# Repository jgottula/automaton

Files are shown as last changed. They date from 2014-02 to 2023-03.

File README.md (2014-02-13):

automaton
=========
`automaton` is a trip computer for your car. Utilizing breakthrough 1990s
technology, it will enable instantaeous visibility into various aspects of your
car's performance, such as engine data, fuel efficiency estimates, and speed
statistics. In addition, state-of-the-art SD card technology is now enabling the
sort of data logging and analysis that bored drivers of the past could only
dream about. `automaton` will undoubtably provide multiple hours of fun to
offset the innumerable hours its users spend driving.

what is it
----------
**Hardware** currently consists of a professionally fabricated PCB, mounted in a
sturdy project box with an RGB-backlit 128x64 graphics LCD for output and a
series of pushbuttons for input. IO connections on the board include **OBD-II**
(of course), **MicroSD** (for data logging), **MiniUSB** (for debug logging),
**JTAG** (for programming/debugging), and **PDI** (also for
programming/debugging).

**Firmware** consists of the AVR Xmega firmware program written in C that
operates the primary microcontroller.

**Software** will consist of PC-based Python scripts that can analyze logged
data to produce graphs and other statistical eye candy.

project status
--------------
**Hardware** is in its third version: first came the breadboard version that
used an AVR ATmega and the STN1110 OBD chip; second came a largely similar, but
more permanent, iteration built on perfboard; and now, the hardware is on a PCB
as described in the previous section. Hardware is essentially finalized, but a
second revision of the PCB may be produced if enough errata are found in the
first.

**Firmware** is where development is currently taking place. This is where most
of the work will be done, and a great deal of code needs to be ported over from
the older version.

**Software** is currently vaporware. Once the firmware is producing data, then
the software can be developed to analyze it.

supported vehicles
------------------
Vehicles must support OBD-II. Any vehicle made after 1996 is required by law to
implement OBD-II. However, the geniuses behind this standard decided that no
less than a half-dozen different physical layer implementations needed to be
developed to transmit the exact same information.

This means that vehicle support is limited by the type of bus in use. Vehicles
made after 2008 are required to support CAN (ISO 15765), so that is what the
current version of `automaton` supports. Future versions could feasibly support
more bus standards, pending developer motivation.

planned features
----------------

- Live data via LCD
- Deferred data analysis via micro SD card and Python scripts
- GPS waypoint logging
- Check Engine Light zapper
- Undocumented OBD-II PID sweeper

hardware and chips
------------------

Hardware is subject to change, but it's pretty locked down at this point.

- Microcontroller: Atmel ATxmega128A3U @ 32MHz (128KB flash; 8KB SRAM)
- CAN transceiver: Microchip MCP2562
- CAN controller: Microchip MCP2515
- Real-time clock: Maxim DS1390U
- GPS module: GlobalTop FGPMMOPA6H
- Debug UART: FTDI FT231XS
- LCD: 128x64 ST7565 graphic RGB-backlit LCD

compiling
---------
This project uses Avery Pennarun's implementation of D. J. Bernstein's `redo`
build system.

To build the `automaton` AVR firmware program, install `redo` and simply run
`redo all`. To clean the project directory, run `redo clean`.

To load the firmware onto the microcontroller, obtain a hardware programmer and
run `redo load`. You will almost certainly need to modify the build script for
this to work.

The build script may need to be modified for your system configuration. To do
so, you need only edit the `default.do` file in the project's root directory. As
`redo` uses posix shell scripts, a basic understanding of shell scripting is
sufficient to modify the build script to your purposes.

license
-------
This project is licensed under the terms of the simplified (2-clause) BSD
license. For more information, see the `LICENSE` file contained in the project's
root directory.

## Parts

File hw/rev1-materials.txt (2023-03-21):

bill of materials

digikey		WebID 50408393, AccessID 27979
adafruit	FGPMMOPA6H, LCD
mdfly		6x6x9 buttons, button caps
frys		idc 12-pin crimp connectors
home depot	velcro mount
lowes		PCB screws
my stuff	78L05, headers, ribbon cable

costs:
osh park	$53.65 (3x PCB r1)
digikey		~$49.94 (1x Bill of matls) + ~8.07 (replacement LED & microSD)
			+ ~$14.95 (GPS antenna and SMA connector)
adafruit	$18.95+ (1x LCD)
adafruit	$33.77 (1x GPS)
home depot	$3.21 (1x Velcro 4x2" Industrial StrengthStrips)
lowes		$4.46 (20x #4x1/4" PCB screw)
frys		$ ()

enclosure		1591XXCBK
	alt:		1951XXCSBK (econo version)
	alt:		1591XXBBK (slightly smaller)
pcb screw		6004 (qty: 4)
power supply	R-78E3.3-0.5
	alt:		ROF-78E3.3-0.5SMD-R
5v regulator	L78L05ACZ
avr xmega		ATXMEGA128A3U
lcd				adafruit st7565 128x64 rgb negative (owned already)
gps				FGPMMOPA6H
	alt:		Venus638FLPx-L
can controller	MCP2515
can transceiver	MCP2562
usb/serial		FT231XS
rtc				DS1390U-33+T&R
usb port		0675031020
sd socket		5031820832 (NOT 5033980891!)
battery holder	BLP2032SM-GTR (rather large... smaller batt or vertical holder?)
avr xtal		ATS16B
can xtal		ATS250B-E
rtc xtal		CFS206-32.768KEZB
button			B3F-1050
	cap:		B32-2000/B32-2010 (5mm round)
	cap:		B32-1060/B32-1010 (4mm square)
reset button	???
piezo			???
power switch	???

NEED: 12-pin IDC ribbon cable terminator (female) for LCD connection (11 pins)

LED 1206 R/1.8	LH N974-KN-1
LED 1206 G/2.2	LG N971-KN-1

R 1206    12	RC3216J120CS
R 1206    27	RC3216J270CS
R 1206    68	RC3216J680CS
R 1206   120	RC3216J121CS
R 1206    1k	RC3216J102CS
R 1206  1.5k	RC3216J152CS
R 1206  4.7k	RC3216J472CS
R 1206   10k	RC3216F103CS

C 1206 5.6pF	CL31C5R6CBCNNNC
C 1206  18pF	CL31C180JBCNNNC
C 1206  47pF	CL31C470JCCNNNC
C 1206   1nF	CL31B102KBCNNNC
C 1206  10nF	CL31B103KBCNNNC
C 1206 100nF	CL31B104KBCNNNC
C 1206 330nF	CL31B334KBFNNNE
C 1206   1uF	CL31B105KAHNNNE
C 1206 4.7uF	CL31F475ZOFNNNE
C 2x5  4.7uF	ESH475M050AC3AA
C 2x5   10uF	ESK106M016AC3AA

L 1812  bead	HF50ACB453215-T
L 1812  10uH	CM453232-100KL

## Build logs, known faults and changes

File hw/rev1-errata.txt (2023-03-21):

rev1 errata

major

- GPS UART pin assignments on the XMEGA are idiotic (should be GPS_TX on PD2 and
  GPS_RX on PD3)
  - WORKAROUND: cut PD1, PD2, PD3, rewire so that PD1 is CAN_STANDY, and PD2 and 
    PD3 are GPS_TX and GPS_RX

- Upper-right PCB mount hole should be at (99.5, 51) mm but is actually at
  (99.5, 50) mm
  - WORKAROUND: use 3 mounting screws

- MOSFETs for LCD backlight are all wrong: currently they have drain connected
  to +3.3V and source connected thru resistor to BL- pin; should have source
  connected to GND, and drain connected to resistor/BL- pin
  - WORKAROUND: use MCU IO ports directly

minor

- Insufficient clearance between the 3.3v regulator and the box of the OBD
  right-angle header (very tight clearance with 5v regulator as well)

- USB connector protrudes too far: makes inserting PCB into box difficult

- Battery connector impinges on capacitor to the right; also, the negative
  terminal is completely beneath the plastic and therefore difficult to solder

- Reset button solder pads are too tiny (don't extend out enough) to make good
  electrical connections

- LED resistors are too high-value: switch to 110ohm for green (FTDI RX, pwr)
  and 150ohm for red (FTDI TX)

- Need to label all headers ("JTAG", "LCD", etc) AND label all pin 1's

- Add test points for all voltages (GND, 3V3, 5V, 12V)

- Add SMA/MCX connector for GPS external antenna (APAMP-107 for $7.80)

- Pads for MicroSD detect/ground terminals are too tiny

- Reconsider which ports need to be externally accessible thru side of box;
  consider making ports on the backside of the PCB that protrude thru box bottom

- Add convenient header for non-car power supply

component changes

- Mini USB connector: switch for one that's easier to solder
  - switch to micro USB (even type C?) if possible

- Battery connector: switch for one that's easier to solder (upright?)

- Crystals: use smaller package

- Capacitors: don't use shitty thru-hole electrolytics

features

- Input phy for OBD signal protocols other than CAN (test these with breadboard)
  - SAE J1850 PWM
  - SAE J1850 VPW
  - ISO 9141-2 (same phy as ISO 14230 KWP2000)

- Battery sense analog input
  - use precision resistors for voltage divider
  - base it on STN1110 figure 5

protection

- Power inputs (before regulation)
  - overcurrent: fuse/resistor
  - reversal: blocking diode
  - overvoltage: zener diode
  - ESD: TVS diode

- Vcc power rails (3.3 and 5.0)
  - reversal: blocking diode
  - overvoltage: zener diode

- External IO pins
  - overcurrent: fuse/resistor
  - overvoltage: zener diode (make sure that this won't mess up bus stuff!)
  - ESD: zener diodes (see STN1110 datasheet)

- AVR reset pin
  - overcurrent: 1k resistor directly on RESET pin

- Make sure that all LCD input/output is up to spec

- Check all IC datasheets and ensure that caps & inductors are up to spec

- Use low-ESR caps for all power caps

CHECK THESE THINGS!

- All actual component footprints: check for overlaps!

- Pin headers need pin 1 marked in silkscreen

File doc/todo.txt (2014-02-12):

automaton
todo list

ui pages:
- trouble code viewer
- trouble code clearer
- proprietary PID scanner
  (brute force modes and PIDs; try the AT MA command, page 40 of the ELM327 ds)
  (also try AT SH to address commands to other bus endpoints/controllers)

power saving, in order of savings:
- AVR: turn off peripherals not in use
- AVR idle: use low-power mode
- screen off
- sleep mode: put STN and AVR in low-power mode
- off switch
- disconnect obd cable

graphs:
- use partial vertical blocks to do bar graphs

grouping:
- put die, reset, wdt, power stuff under one directory
- keep mcusr value in there somewhere

clock/voltage:
- run at 3.3V
  - done
    - switch crystal from 20MHz to 12MHz
    - resolder FTDI: 3V out, 3V signal level
    - change F_CPU
    - rewire regulators
    - LCD to 5V
    - MCP2551 to 5V
    - brownout detect level to 2.7
    - remove 4050
    - update time-based enums
  - to do
    - LED resistors

alarm:
- use the same timer for multiple alarms

pc uart:
- variadic logging function with log level parameter?
- use ANSI colors for different log levels

code:
- handle all TODO's and #warning's
- standard greppable comment for REMOVE ME etc

debug:
- in UART code, _BREAK() then die() on errors (eg: dev is neither 0 nor 1)

avarice:
- recompile with atmega324a support

redo:
- load: program the eeprom
- *.o:  do .dep generation in one step (as in manual)
- when avr-gcc-4.8 is fixed, add:
  - -Waddr-space-convert
  - -fno-diagnostics-show-caret

button:
- read up and get RC values for hw debounce

algo/fifo & io/uart:
- read assembly generated by gcc and ensure that atomic/interrupt-safe functions
  don't take dangerous shortcuts and also don't over-access memory

storage:
- replace fat32 with something that won't explode if the power goes out
- my idea: append-only filesystem for logging:
  - two superblocks, updated alternately, with revision number and checksum
  - use most recent version that is valid
  - superblock says what the latest valid block is
  - to append a block: do the write, then update the superblock
  - worst case, lose the latest block only

time:
- add profiling interface
  - use TIMER1 to count cycles, probably
  - profiling targets:
    - all ISRs (especially TIMER0_COMPA with button_update)
    - all delay/alarm code (test for correctness)

lcd/hd44780:
- implement timeout for hd44780_busy_wait
- use 4-bit bus

lcd/lcd:
- make friendly functions to manipulate individual bits of param state
- custom font api

stdio:
- implement a smaller/simpler vfprintf(); override?

power:
- use sleep instead of spinning or _delay_xx
- go to 3.3 volts

hardware:
- use leds everywhere
  - power
  - tx/rx on each UART
  - tx/rx on each OBD interface
  - r/w on SDcard
  - sck on SPI bus
  - buttons?

test:
- time/alarm
- algo/fifo
- io/uart
- io/spi
- lcd/hd44780

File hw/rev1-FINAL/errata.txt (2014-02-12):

rev3 errata

1. GPS UART pin assignments on the XMEGA are idiotic (should be GPS_TX on PD2
   and GPS_RX on PD3)
   MITIGATION: cut PD1, PD2, PD3, rewire so that PD1 is CAN_STANDY, and PD2 and
   PD3 are GPS_TX and GPS_RX (not easy but probably doable)
   MITIGATION: bitbang the uart (nope)

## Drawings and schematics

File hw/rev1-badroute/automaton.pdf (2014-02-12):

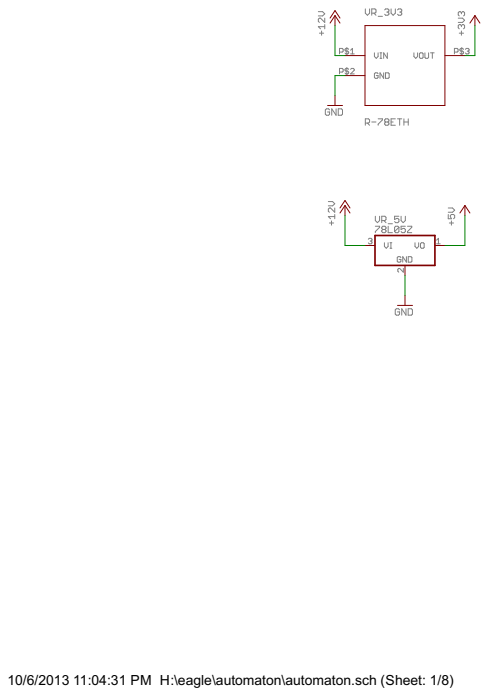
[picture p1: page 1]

10/6/2013 11:04:31 PM H:\eagle\automaton\automaton.sch (Sheet: 1/8)

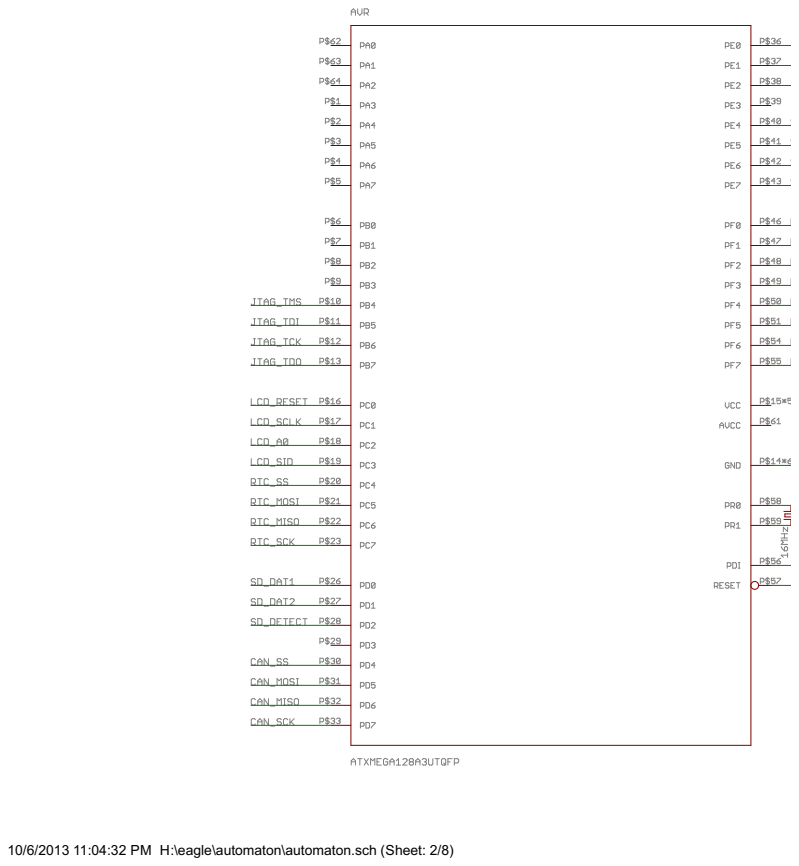
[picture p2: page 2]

10/6/2013 11:04:32 PM H:\eagle\automaton\automaton.sch (Sheet: 2/8)

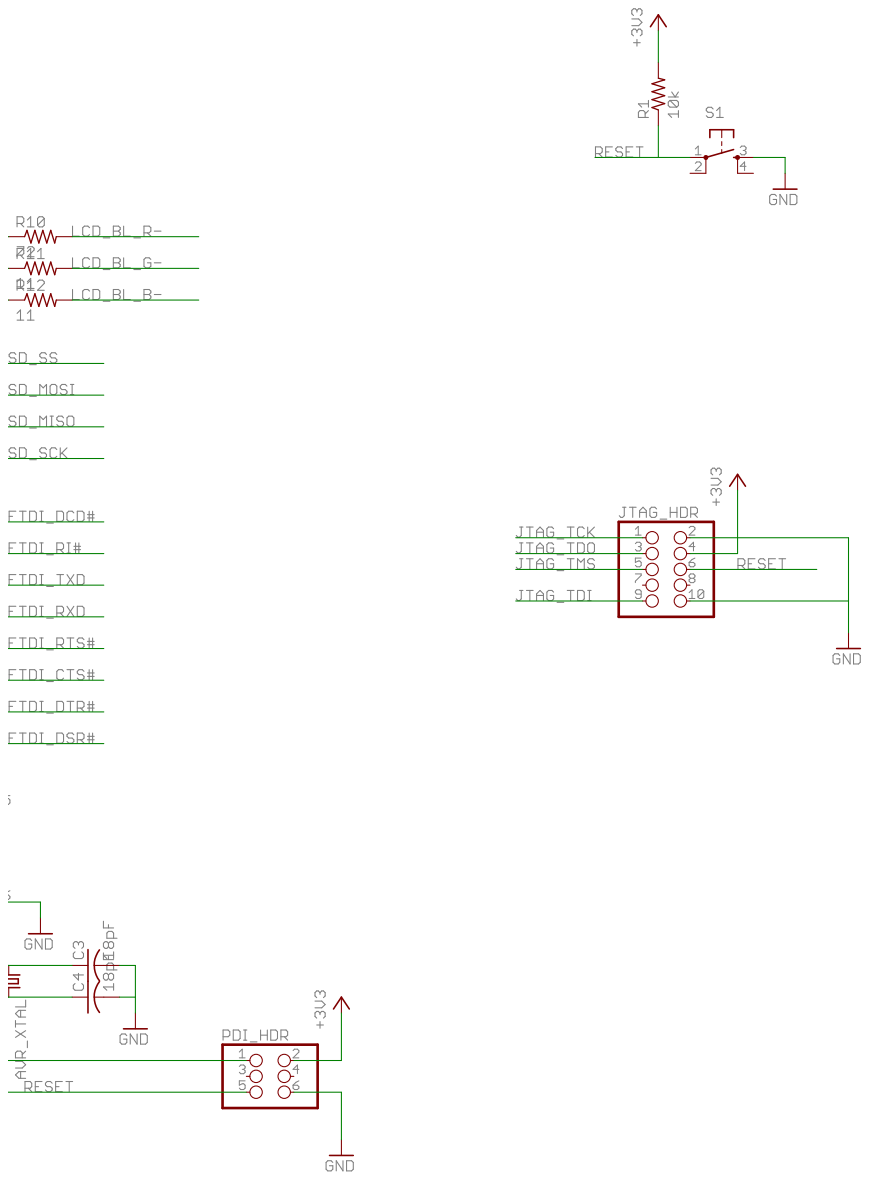
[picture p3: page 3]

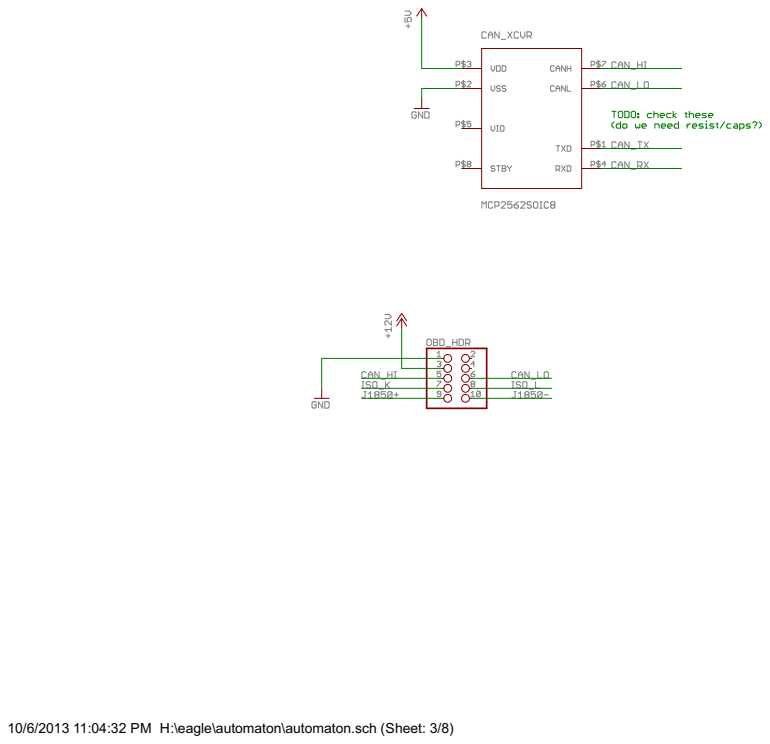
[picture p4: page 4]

10/6/2013 11:04:32 PM H:\eagle\automaton\automaton.sch (Sheet: 3/8)

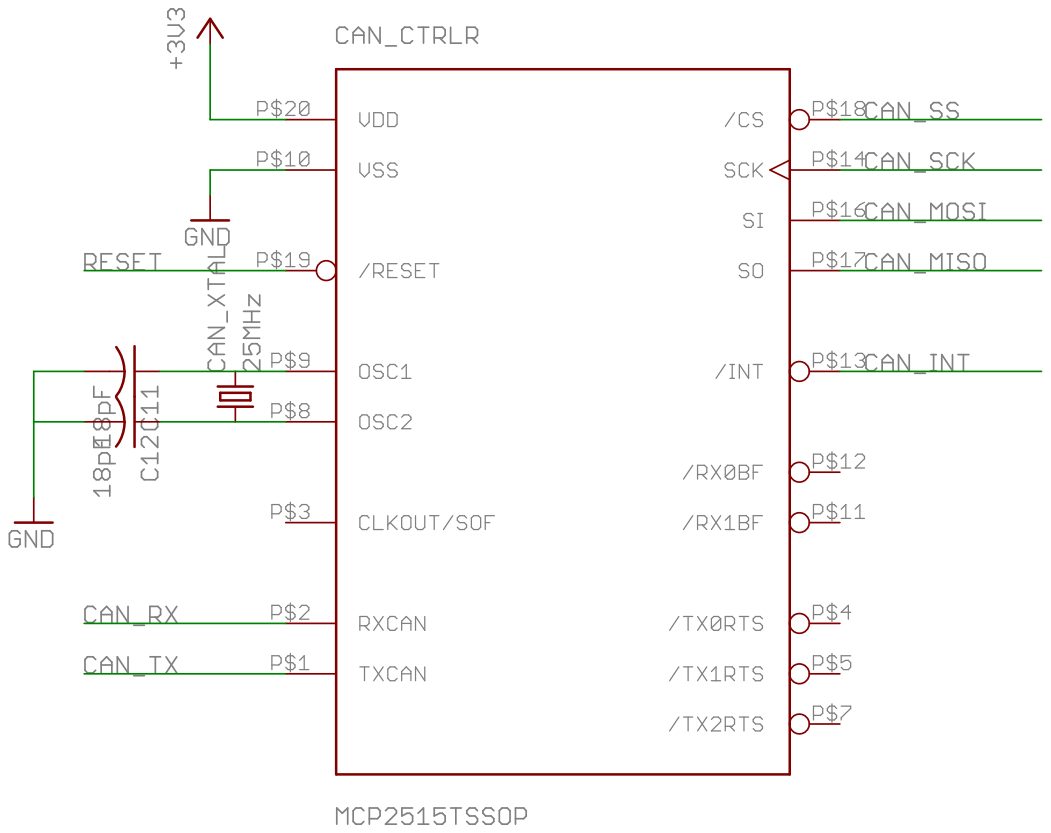
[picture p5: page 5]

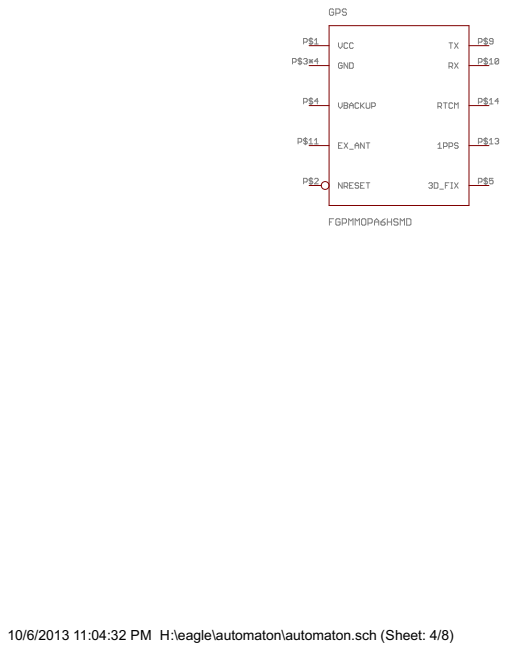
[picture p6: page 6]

10/6/2013 11:04:32 PM H:\eagle\automaton\automaton.sch (Sheet: 4/8)

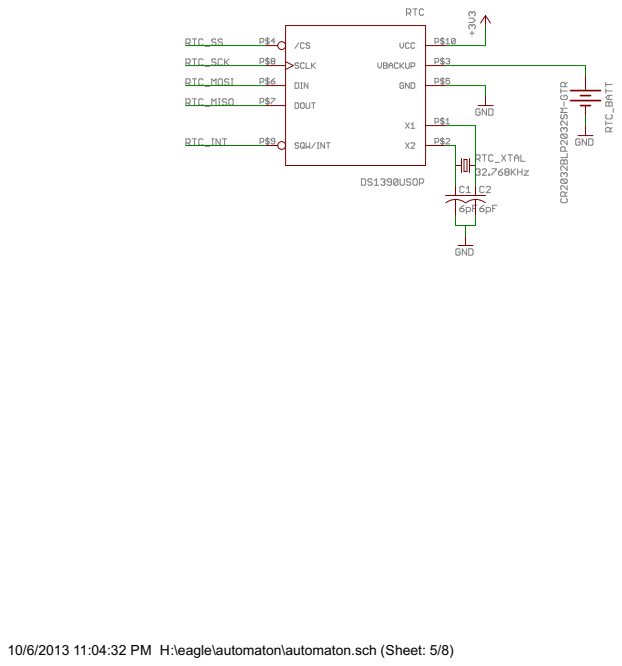
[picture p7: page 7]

10/6/2013 11:04:32 PM H:\eagle\automaton\automaton.sch (Sheet: 5/8)

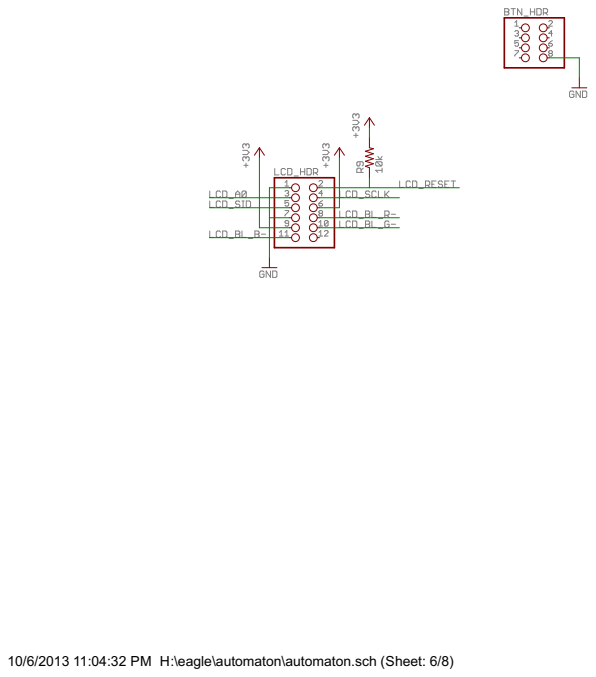
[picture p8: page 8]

10/6/2013 11:04:32 PM H:\eagle\automaton\automaton.sch (Sheet: 6/8)

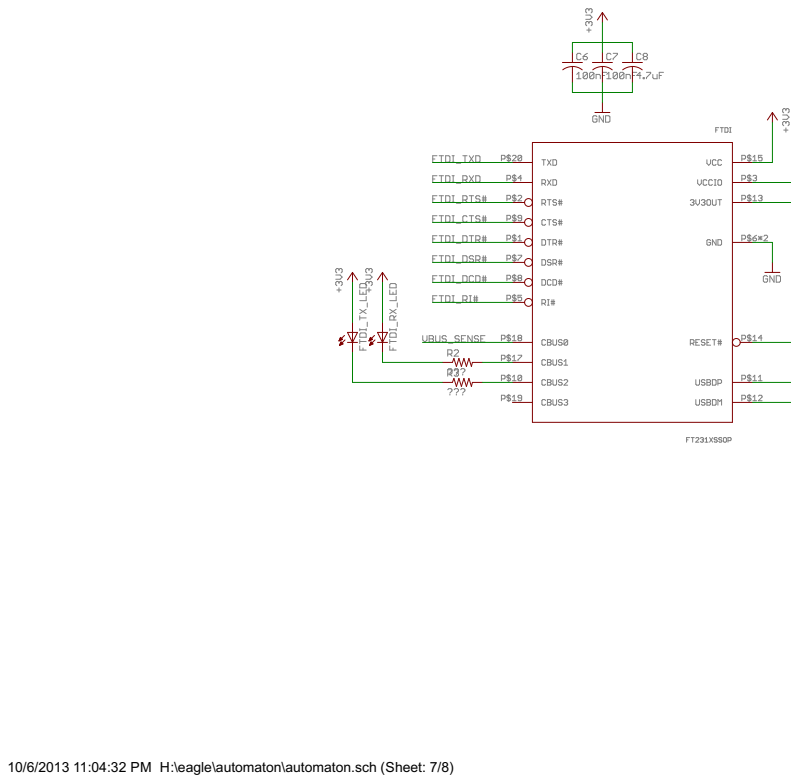
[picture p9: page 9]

10/6/2013 11:04:32 PM H:\eagle\automaton\automaton.sch (Sheet: 7/8)

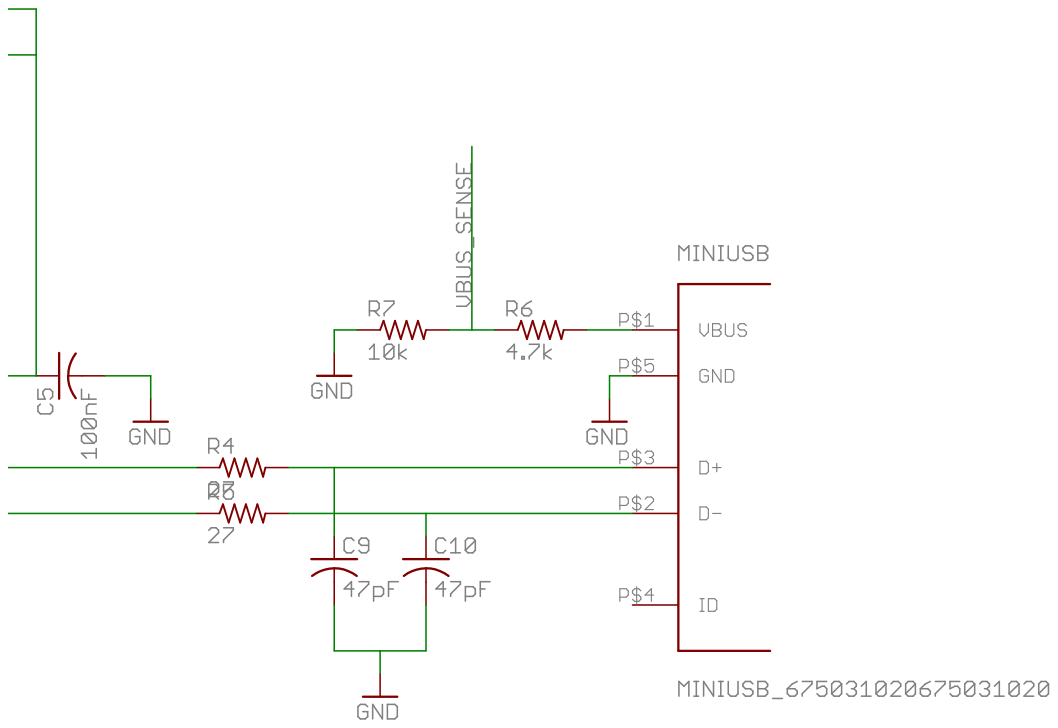
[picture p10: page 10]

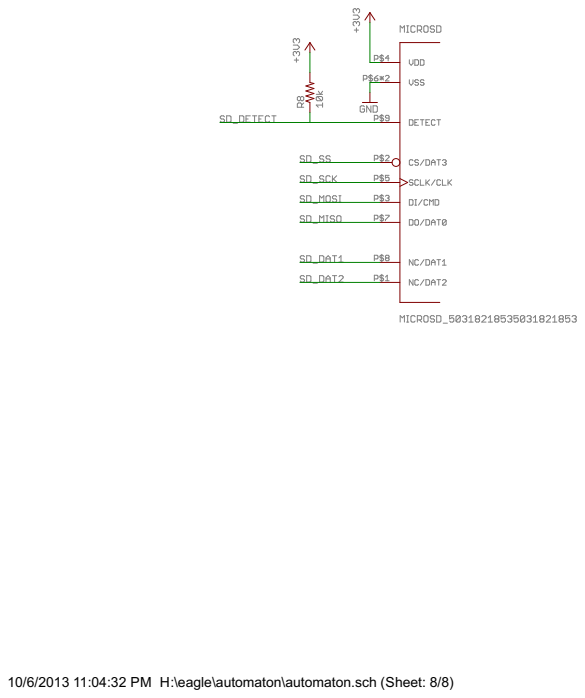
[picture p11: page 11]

10/6/2013 11:04:32 PM H:\eagle\automaton\automaton.sch (Sheet: 8/8)

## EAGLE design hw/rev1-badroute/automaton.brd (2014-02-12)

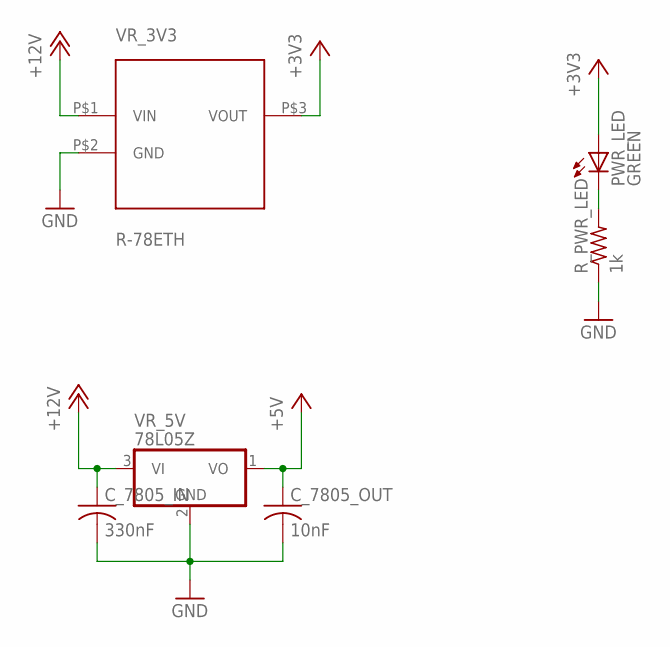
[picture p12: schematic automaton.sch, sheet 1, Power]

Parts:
C_7805_IN: 330nF; C1206
C_7805_OUT: 10nF; C1206
PWR_LED: GREEN; CHIPLED_1206
R_PWR_LED: 1k; R1206
VR_3V3: R-78ETH; R-78E
VR_5V: 78L05Z; TO92

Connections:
+3V3: PWR_LED.A, VR_3V3.P$3 (VOUT); also elsewhere on the board
+5V: C_7805_OUT.1, VR_5V.1 (VO); also elsewhere on the board
+12V: C_7805_IN.1, VR_3V3.P$1 (VIN), VR_5V.3 (VI); also elsewhere on the board
GND: C_7805_IN.2, C_7805_OUT.2, R_PWR_LED.1, VR_3V3.P$2 (GND), VR_5V.2 (GND); also elsewhere on the board
unnamed: PWR_LED.C, R_PWR_LED.2

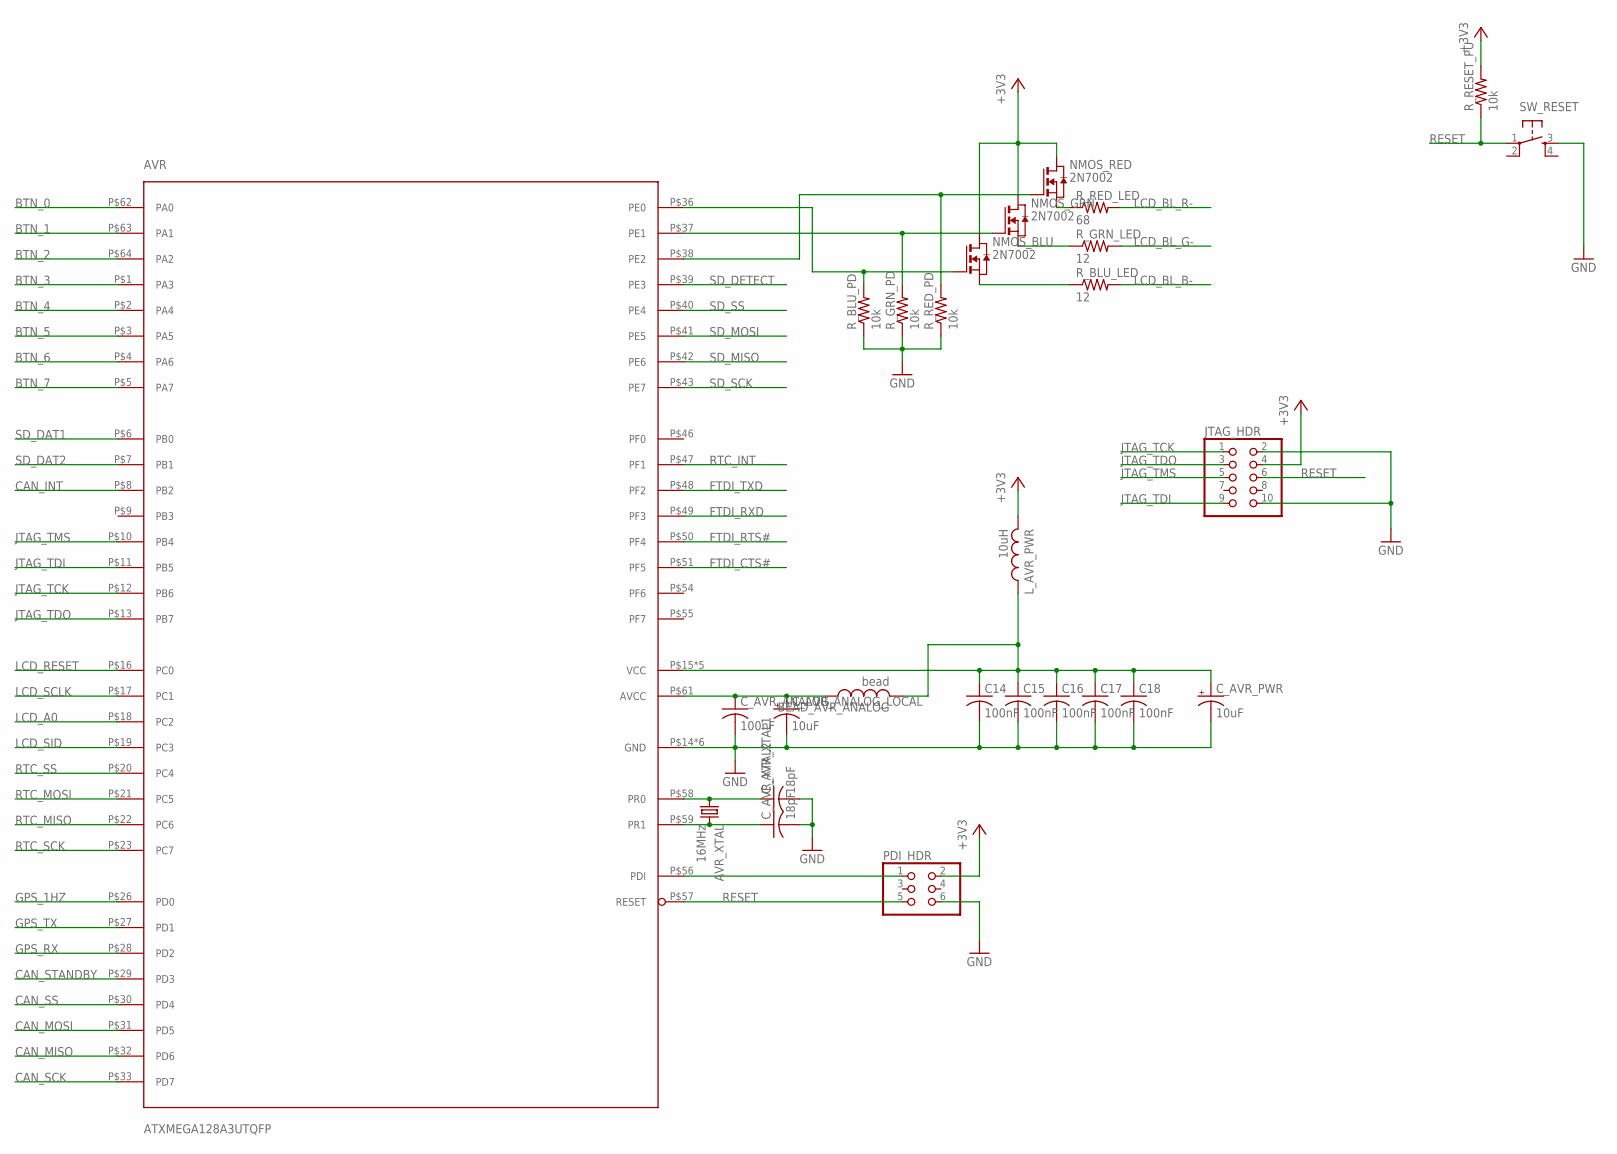
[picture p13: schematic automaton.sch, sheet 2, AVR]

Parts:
AVR: ATXMEGA128A3UTQFP; ATMEL_TQFP64
AVR_XTAL: 16MHz; HC49/S
BEAD_AVR_ANALOG: bead; L1812
C14, C15, C16, C17, C18: 100nF; C1206
C_AVR_ANALOG: 100nF; C1206
C_AVR_ANALOG_LOCAL: 10uF; E2-5
C_AVR_PWR: 10uF; E2-5
C_AVR_XTAL1, C_AVR_XTAL2: 18pF; C1206
JTAG_HDR: PINHD-2X05_2.54; 2X05
L_AVR_PWR: 10uH; L1812
NMOS_BLU: 2N7002; SOT-23
NMOS_GRN: 2N7002; SOT-23
NMOS_RED: 2N7002; SOT-23
PDI_HDR: PINHD-2X03_2.54; 2X03
R_BLU_LED: 12; R1206
R_BLU_PD: 10k; R1206
R_GRN_LED: 12; R1206
R_GRN_PD: 10k; R1206
R_RED_LED: 68; R1206
R_RED_PD: 10k; R1206
R_RESET_PU: 10k; R1206
SW_RESET: TAC_SWITCHSMD; TACTILE_SWITCH_SMD

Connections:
+3V3: JTAG_HDR.4, L_AVR_PWR.2, NMOS_BLU.1 (D), NMOS_GRN.1 (D), NMOS_RED.1 (D), PDI_HDR.2, R_RESET_PU.2; also elsewhere on the board
BTN_0: AVR.P$62 (PA0); also elsewhere on the board
BTN_1: AVR.P$63 (PA1); also elsewhere on the board
BTN_2: AVR.P$64 (PA2); also elsewhere on the board
BTN_3: AVR.P$1 (PA3); also elsewhere on the board
BTN_4: AVR.P$2 (PA4); also elsewhere on the board
BTN_5: AVR.P$3 (PA5); also elsewhere on the board
BTN_6: AVR.P$4 (PA6); also elsewhere on the board
BTN_7: AVR.P$5 (PA7); also elsewhere on the board
CAN_INT: AVR.P$8 (PB2); also elsewhere on the board
CAN_MISO: AVR.P$32 (PD6); also elsewhere on the board
CAN_MOSI: AVR.P$31 (PD5); also elsewhere on the board
CAN_SCK: AVR.P$33 (PD7); also elsewhere on the board
CAN_SS: AVR.P$30 (PD4); also elsewhere on the board
CAN_STANDBY: AVR.P$29 (PD3); also elsewhere on the board
FTDI_CTS#: AVR.P$51 (PF5); also elsewhere on the board
FTDI_RTS#: AVR.P$50 (PF4); also elsewhere on the board
FTDI_RXD: AVR.P$49 (PF3); also elsewhere on the board
FTDI_TXD: AVR.P$48 (PF2); also elsewhere on the board
GND: AVR.P$14 (GND), AVR.P$24 (GND), AVR.P$34 (GND), AVR.P$44 (GND), AVR.P$52 (GND), AVR.P$60 (GND), C14.2, C15.2, C16.2, C17.2, C18.2, C_AVR_ANALOG.2, C_AVR_ANALOG_LOCAL.-, C_AVR_PWR.-, C_AVR_XTAL1.2, C_AVR_XTAL2.2, JTAG_HDR.2, JTAG_HDR.10, PDI_HDR.6, R_BLU_PD.1, R_GRN_PD.1, R_RED_PD.1, SW_RESET.3; also elsewhere on the board
GPS_1HZ: AVR.P$26 (PD0); also elsewhere on the board
GPS_RX: AVR.P$28 (PD2); also elsewhere on the board
GPS_TX: AVR.P$27 (PD1); also elsewhere on the board
JTAG_TCK: AVR.P$12 (PB6), JTAG_HDR.1
JTAG_TDI: AVR.P$11 (PB5), JTAG_HDR.9
JTAG_TDO: AVR.P$13 (PB7), JTAG_HDR.3
JTAG_TMS: AVR.P$10 (PB4), JTAG_HDR.5
LCD_A0: AVR.P$18 (PC2); also elsewhere on the board
LCD_BL_B-: R_BLU_LED.2; also elsewhere on the board
LCD_BL_G-: R_GRN_LED.2; also elsewhere on the board
LCD_BL_R-: R_RED_LED.2; also elsewhere on the board
LCD_RESET: AVR.P$16 (PC0); also elsewhere on the board
LCD_SCLK: AVR.P$17 (PC1); also elsewhere on the board
LCD_SID: AVR.P$19 (PC3); also elsewhere on the board
unnamed: AVR.P$58 (PR0), AVR_XTAL.1, C_AVR_XTAL1.1
unnamed: AVR.P$59 (PR1), AVR_XTAL.2, C_AVR_XTAL2.1
unnamed: AVR.P$37 (PE1), NMOS_GRN.3 (G), R_GRN_PD.2
unnamed: AVR.P$36 (PE0), NMOS_BLU.3 (G), R_BLU_PD.2
unnamed: AVR.P$61 (AVCC), BEAD_AVR_ANALOG.1, C_AVR_ANALOG.1, C_AVR_ANALOG_LOCAL.+
unnamed: AVR.P$38 (PE2), NMOS_RED.3 (G), R_RED_PD.2
unnamed: AVR.P$15 (VCC), AVR.P$25 (VCC), AVR.P$35 (VCC), AVR.P$45 (VCC), AVR.P$53 (VCC), BEAD_AVR_ANALOG.2, C14.1, C15.1, C16.1, C17.1, C18.1, C_AVR_PWR.+, L_AVR_PWR.1
unnamed: NMOS_BLU.2 (S), R_BLU_LED.1
unnamed: NMOS_GRN.2 (S), R_GRN_LED.1
unnamed: NMOS_RED.2 (S), R_RED_LED.1
PDI_DATA: AVR.P$56 (PDI), PDI_HDR.1
RESET: AVR.P$57 (RESET), JTAG_HDR.6, PDI_HDR.5, R_RESET_PU.1, SW_RESET.1
RTC_INT: AVR.P$47 (PF1); also elsewhere on the board
RTC_MISO: AVR.P$22 (PC6); also elsewhere on the board
RTC_MOSI: AVR.P$21 (PC5); also elsewhere on the board
RTC_SCK: AVR.P$23 (PC7); also elsewhere on the board
RTC_SS: AVR.P$20 (PC4); also elsewhere on the board
SD_DAT1: AVR.P$6 (PB0); also elsewhere on the board
SD_DAT2: AVR.P$7 (PB1); also elsewhere on the board
SD_DETECT: AVR.P$39 (PE3); also elsewhere on the board
SD_MISO: AVR.P$42 (PE6); also elsewhere on the board
SD_MOSI: AVR.P$41 (PE5); also elsewhere on the board
SD_SCK: AVR.P$43 (PE7); also elsewhere on the board
SD_SS: AVR.P$40 (PE4); also elsewhere on the board

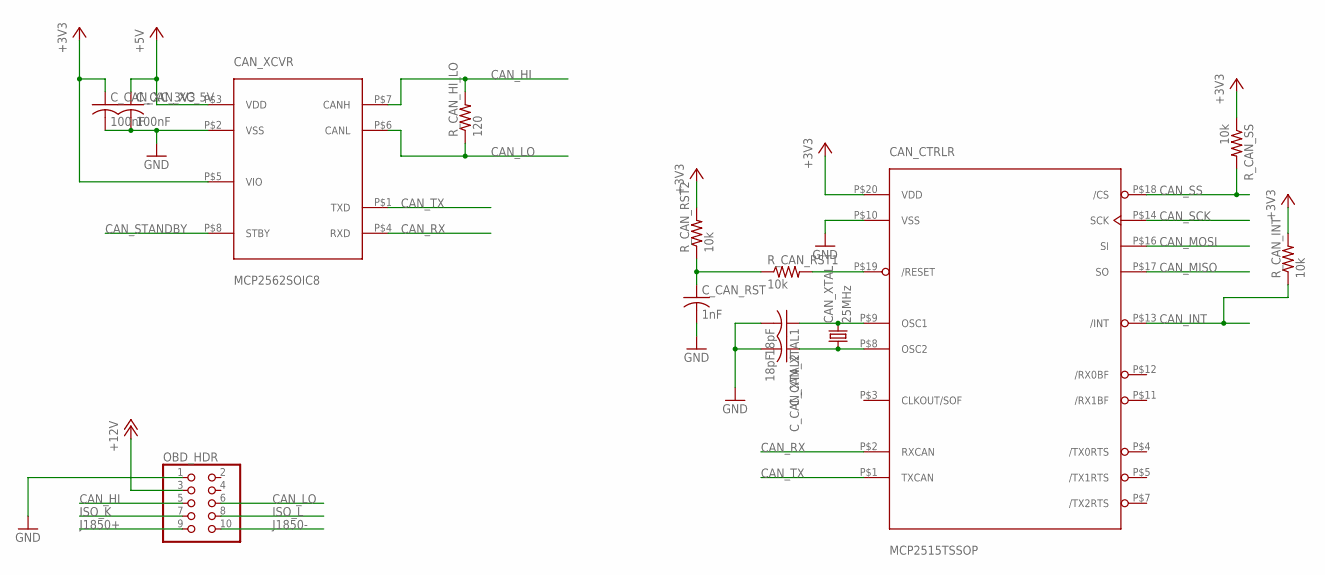
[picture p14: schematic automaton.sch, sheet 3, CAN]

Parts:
CAN_CTRLR: MCP2515TSSOP; MICROCHIP_TSSOP20
CAN_XCVR: MCP2562SOIC8; MICROCHIP_SOIC8
CAN_XTAL: 25MHz; HC49/S
C_CAN_RST: 1nF; C1206
C_CAN_XC_3V3, C_CAN_XC_5V: 100nF; C1206
C_CAN_XTAL1, C_CAN_XTAL2: 18pF; C1206
OBD_HDR: PINHD-2X05_2.54-90°; 2X05/90
R_CAN_HI_LO: 120; R1206
R_CAN_INT: 10k; R1206
R_CAN_RST1, R_CAN_RST2: 10k; R1206
R_CAN_SS: 10k; R1206

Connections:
+3V3: CAN_CTRLR.P$20 (VDD), CAN_XCVR.P$5 (VIO), C_CAN_XC_3V3.1, R_CAN_INT.2, R_CAN_RST2.2, R_CAN_SS.1; also elsewhere on the board
+5V: CAN_XCVR.P$3 (VDD), C_CAN_XC_5V.1; also elsewhere on the board
+12V: OBD_HDR.3; also elsewhere on the board
CAN_HI: CAN_XCVR.P$7 (CANH), OBD_HDR.5, R_CAN_HI_LO.2
CAN_INT: CAN_CTRLR.P$13 (/INT), R_CAN_INT.1; also elsewhere on the board
CAN_LO: CAN_XCVR.P$6 (CANL), OBD_HDR.6, R_CAN_HI_LO.1
CAN_MISO: CAN_CTRLR.P$17 (SO); also elsewhere on the board
CAN_MOSI: CAN_CTRLR.P$16 (SI); also elsewhere on the board
CAN_RX: CAN_CTRLR.P$2 (RXCAN), CAN_XCVR.P$4 (RXD)
CAN_SCK: CAN_CTRLR.P$14 (SCK); also elsewhere on the board
CAN_SS: CAN_CTRLR.P$18 (/CS), R_CAN_SS.2; also elsewhere on the board
CAN_STANDBY: CAN_XCVR.P$8 (STBY); also elsewhere on the board
CAN_TX: CAN_CTRLR.P$1 (TXCAN), CAN_XCVR.P$1 (TXD)
GND: CAN_CTRLR.P$10 (VSS), CAN_XCVR.P$2 (VSS), C_CAN_RST.2, C_CAN_XC_3V3.2, C_CAN_XC_5V.2, C_CAN_XTAL1.2, C_CAN_XTAL2.2, OBD_HDR.1; also elsewhere on the board
ISO_K: OBD_HDR.7
ISO_L: OBD_HDR.8
J1850+: OBD_HDR.9
J1850-: OBD_HDR.10
unnamed: C_CAN_RST.1, R_CAN_RST1.1, R_CAN_RST2.1
unnamed: CAN_CTRLR.P$9 (OSC1), CAN_XTAL.2, C_CAN_XTAL1.1
unnamed: CAN_CTRLR.P$8 (OSC2), CAN_XTAL.1, C_CAN_XTAL2.1
unnamed: CAN_CTRLR.P$19 (/RESET), R_CAN_RST1.2

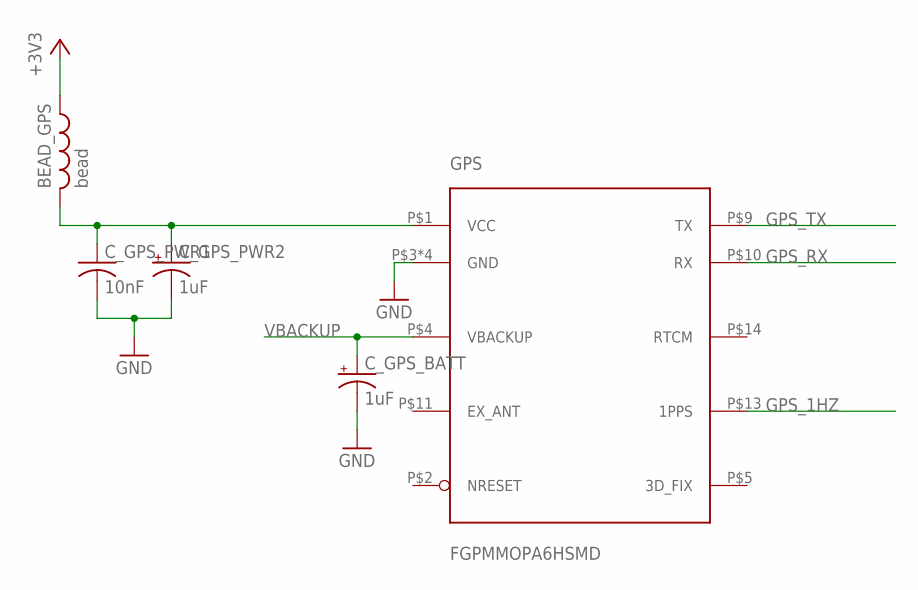
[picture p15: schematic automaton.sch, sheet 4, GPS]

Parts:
BEAD_GPS: bead; L1812
C_GPS_BATT: 1uF; E2-5
C_GPS_PWR1: 10nF; C1206
C_GPS_PWR2: 1uF; E2-5
GPS: FGPMMOPA6HSMD; FGPMMOPA6H

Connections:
+3V3: BEAD_GPS.1; also elsewhere on the board
GND: C_GPS_BATT.-, C_GPS_PWR1.2, C_GPS_PWR2.-, GPS.P$3 (GND), GPS.P$8 (GND), GPS.P$12 (GND), GPS.P$19 (GND); also elsewhere on the board
GPS_1HZ: GPS.P$13 (1PPS); also elsewhere on the board
GPS_RX: GPS.P$10 (RX); also elsewhere on the board
GPS_TX: GPS.P$9 (TX); also elsewhere on the board
unnamed: BEAD_GPS.2, C_GPS_PWR1.1, C_GPS_PWR2.+, GPS.P$1 (VCC)
VBACKUP: C_GPS_BATT.+, GPS.P$4 (VBACKUP); also elsewhere on the board

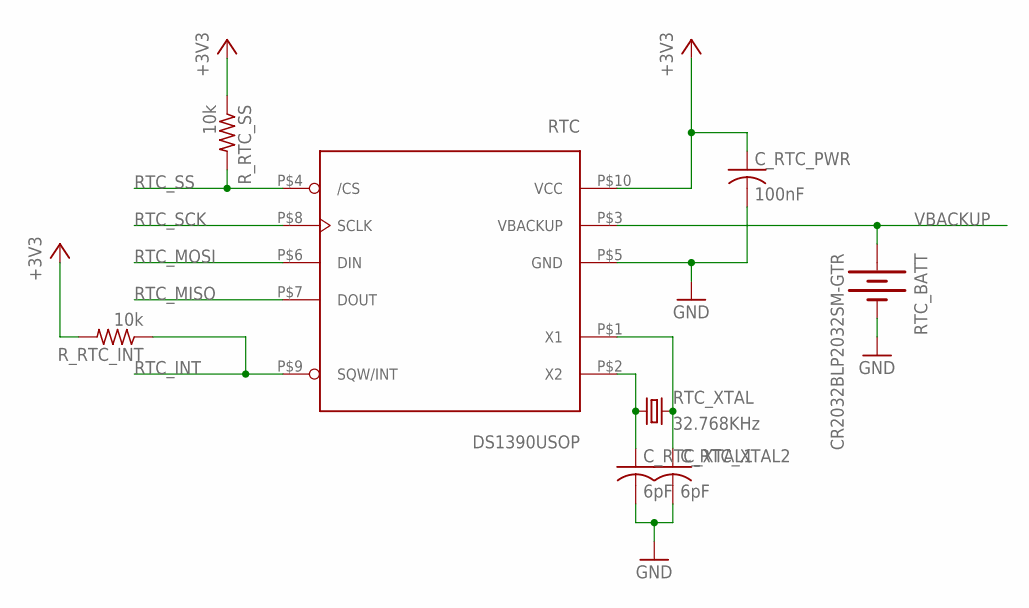
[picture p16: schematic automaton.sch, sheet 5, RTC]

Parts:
C_RTC_PWR: 100nF; C1206
C_RTC_XTAL1, C_RTC_XTAL2: 6pF; C1206
RTC: DS1390USOP; MAXIM_10USOP
RTC_BATT: CR2032BLP2032SM-GTR; BLP2032SM-GTR
RTC_XTAL: 32.768KHz; TC26V
R_RTC_INT: 10k; R1206
R_RTC_SS: 10k; R1206

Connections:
+3V3: C_RTC_PWR.1, RTC.P$10 (VCC), R_RTC_INT.2, R_RTC_SS.1; also elsewhere on the board
GND: C_RTC_PWR.2, C_RTC_XTAL1.2, C_RTC_XTAL2.2, RTC.P$5 (GND), RTC_BATT.P$2 (-); also elsewhere on the board
unnamed: C_RTC_XTAL1.1, RTC.P$2 (X2), RTC_XTAL.1
unnamed: C_RTC_XTAL2.1, RTC.P$1 (X1), RTC_XTAL.2
RTC_INT: RTC.P$9 (SQW/INT), R_RTC_INT.1; also elsewhere on the board
RTC_MISO: RTC.P$7 (DOUT); also elsewhere on the board
RTC_MOSI: RTC.P$6 (DIN); also elsewhere on the board
RTC_SCK: RTC.P$8 (SCLK); also elsewhere on the board
RTC_SS: RTC.P$4 (/CS), R_RTC_SS.2; also elsewhere on the board
VBACKUP: RTC.P$3 (VBACKUP), RTC_BATT.P$1 (+); also elsewhere on the board

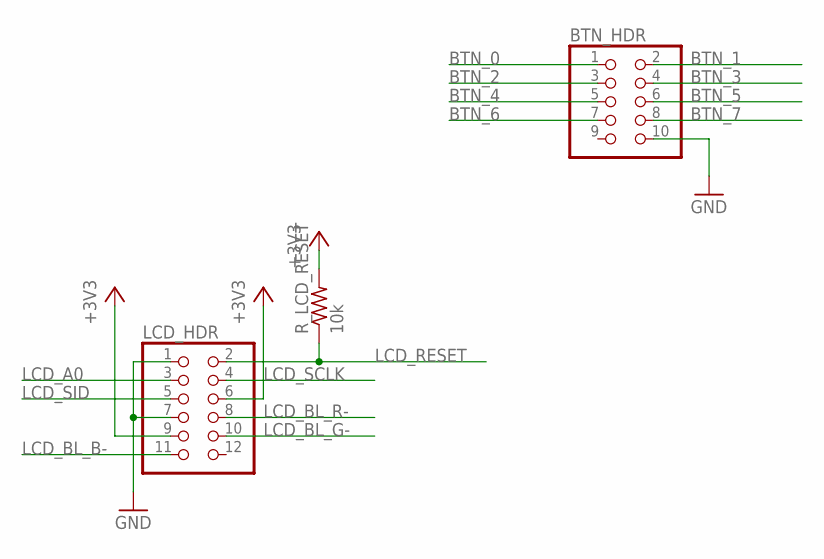
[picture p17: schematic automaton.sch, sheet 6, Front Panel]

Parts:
BTN_HDR: PINHD-2X05_2.54; 2X05
LCD_HDR: PINHD-2X06_2.54; 2X06
R_LCD_RESET: 10k; R1206

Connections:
+3V3: LCD_HDR.6, LCD_HDR.9, R_LCD_RESET.2; also elsewhere on the board
BTN_0: BTN_HDR.1; also elsewhere on the board
BTN_1: BTN_HDR.2; also elsewhere on the board
BTN_2: BTN_HDR.3; also elsewhere on the board
BTN_3: BTN_HDR.4; also elsewhere on the board
BTN_4: BTN_HDR.5; also elsewhere on the board
BTN_5: BTN_HDR.6; also elsewhere on the board
BTN_6: BTN_HDR.7; also elsewhere on the board
BTN_7: BTN_HDR.8; also elsewhere on the board
GND: BTN_HDR.10, LCD_HDR.1, LCD_HDR.7; also elsewhere on the board
LCD_A0: LCD_HDR.3; also elsewhere on the board
LCD_BL_B-: LCD_HDR.11; also elsewhere on the board
LCD_BL_G-: LCD_HDR.10; also elsewhere on the board
LCD_BL_R-: LCD_HDR.8; also elsewhere on the board
LCD_RESET: LCD_HDR.2, R_LCD_RESET.1; also elsewhere on the board
LCD_SCLK: LCD_HDR.4; also elsewhere on the board
LCD_SID: LCD_HDR.5; also elsewhere on the board

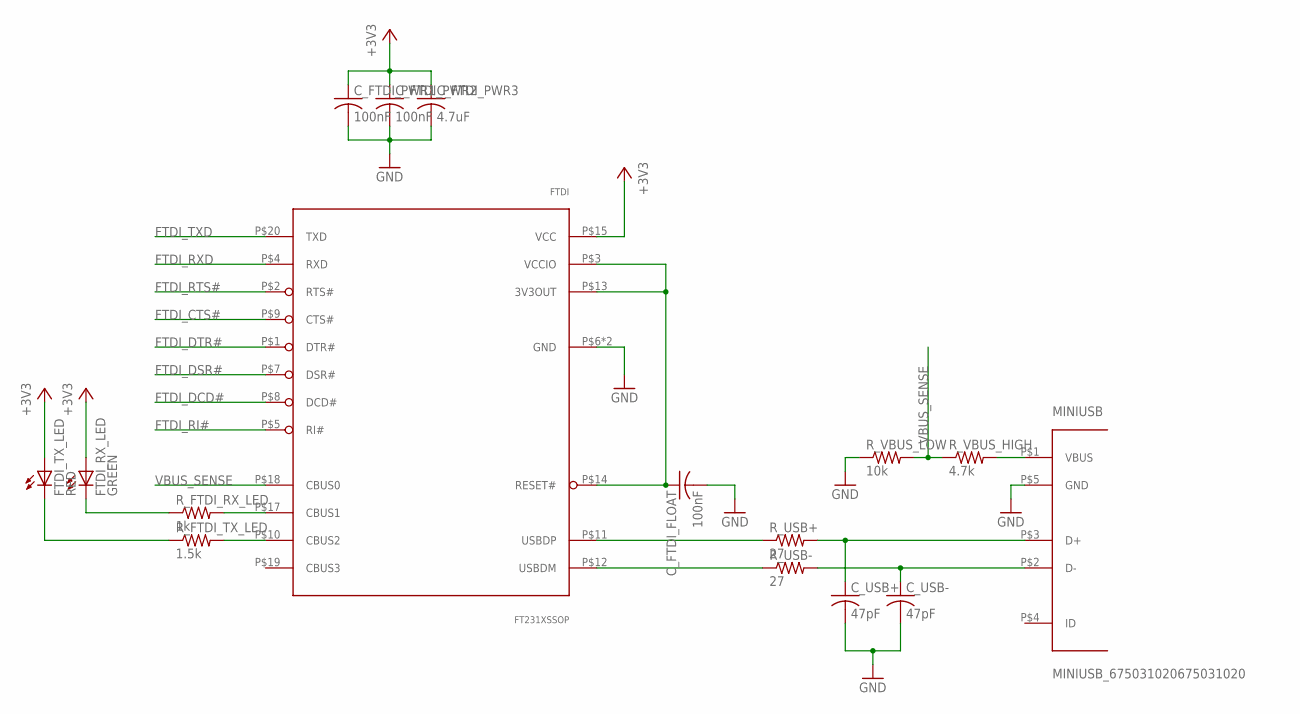
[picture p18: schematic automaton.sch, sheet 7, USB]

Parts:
C_FTDI_FLOAT: 100nF; C1206
C_FTDI_PWR1, C_FTDI_PWR2: 100nF; C1206
C_FTDI_PWR3: 4.7uF; C1206
C_USB+: 47pF; C1206
C_USB-: 47pF; C1206
FTDI: FT231XSSOP; FTDI_SSOP20
FTDI_RX_LED: GREEN; CHIPLED_1206
FTDI_TX_LED: RED; CHIPLED_1206
MINIUSB: MINIUSB_675031020675031020; MINIUSB_675031020
R_FTDI_RX_LED: 1k; R1206
R_FTDI_TX_LED: 1.5k; R1206
R_USB+: 27; R1206
R_USB-: 27; R1206
R_VBUS_HIGH: 4.7k; R1206
R_VBUS_LOW: 10k; R1206

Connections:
+3V3: C_FTDI_PWR1.1, C_FTDI_PWR2.1, C_FTDI_PWR3.1, FTDI.P$15 (VCC), FTDI_RX_LED.A, FTDI_TX_LED.A; also elsewhere on the board
FTDI_CTS#: FTDI.P$9 (CTS#); also elsewhere on the board
FTDI_DCD#: FTDI.P$8 (DCD#)
FTDI_DSR#: FTDI.P$7 (DSR#)
FTDI_DTR#: FTDI.P$1 (DTR#)
FTDI_RI#: FTDI.P$5 (RI#)
FTDI_RTS#: FTDI.P$2 (RTS#); also elsewhere on the board
FTDI_RXD: FTDI.P$4 (RXD); also elsewhere on the board
FTDI_TXD: FTDI.P$20 (TXD); also elsewhere on the board
GND: C_FTDI_FLOAT.2, C_FTDI_PWR1.2, C_FTDI_PWR2.2, C_FTDI_PWR3.2, C_USB+.2, C_USB-.2, FTDI.P$6 (GND), FTDI.P$16 (GND), MINIUSB.P$5 (GND), R_VBUS_LOW.1; also elsewhere on the board
unnamed: C_FTDI_FLOAT.1, FTDI.P$3 (VCCIO), FTDI.P$13 (3V3OUT), FTDI.P$14 (RESET#)
unnamed: FTDI_RX_LED.C, R_FTDI_RX_LED.1
unnamed: FTDI.P$12 (USBDM), R_USB-.1
unnamed: FTDI.P$11 (USBDP), R_USB+.1
unnamed: FTDI_TX_LED.C, R_FTDI_TX_LED.1
unnamed: FTDI.P$10 (CBUS2), R_FTDI_TX_LED.2
unnamed: FTDI.P$17 (CBUS1), R_FTDI_RX_LED.2
unnamed: C_USB+.1, MINIUSB.P$3 (D+), R_USB+.2
unnamed: C_USB-.1, MINIUSB.P$2 (D-), R_USB-.2
unnamed: MINIUSB.P$1 (VBUS), R_VBUS_HIGH.2
VBUS_SENSE: FTDI.P$18 (CBUS0), R_VBUS_HIGH.1, R_VBUS_LOW.2

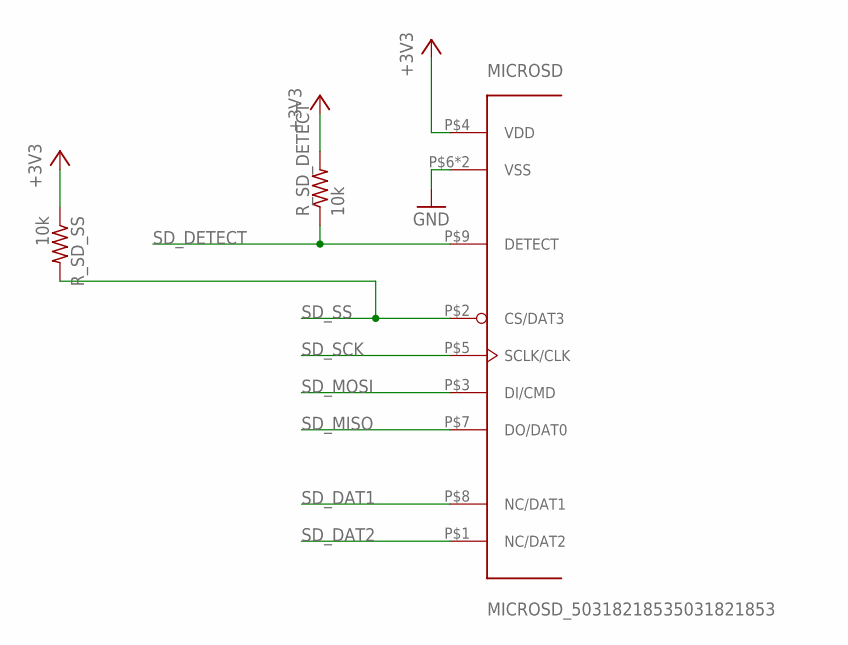
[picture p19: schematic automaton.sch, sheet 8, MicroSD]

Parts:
MICROSD: MICROSD_50318218535031821853; MICROSD_5031821853
R_SD_DETECT: 10k; R1206
R_SD_SS: 10k; R1206

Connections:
+3V3: MICROSD.P$4 (VDD), R_SD_DETECT.2, R_SD_SS.1; also elsewhere on the board
GND: MICROSD.P$6 (VSS), MICROSD.P$10 (VSS); also elsewhere on the board
SD_DAT1: MICROSD.P$8 (NC/DAT1); also elsewhere on the board
SD_DAT2: MICROSD.P$1 (NC/DAT2); also elsewhere on the board
SD_DETECT: MICROSD.P$9 (DETECT), R_SD_DETECT.1; also elsewhere on the board
SD_MISO: MICROSD.P$7 (DO/DAT0); also elsewhere on the board
SD_MOSI: MICROSD.P$3 (DI/CMD); also elsewhere on the board
SD_SCK: MICROSD.P$5 (SCLK/CLK); also elsewhere on the board
SD_SS: MICROSD.P$2 (CS/DAT3), R_SD_SS.2; also elsewhere on the board

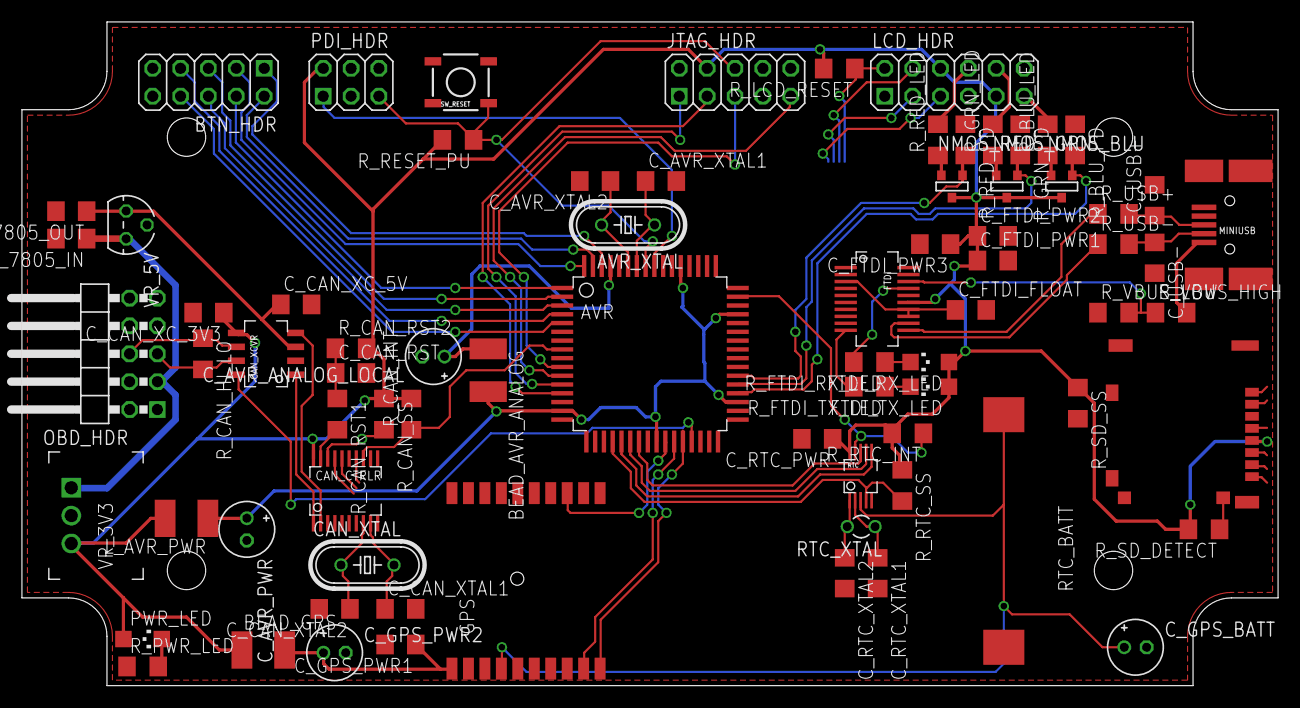
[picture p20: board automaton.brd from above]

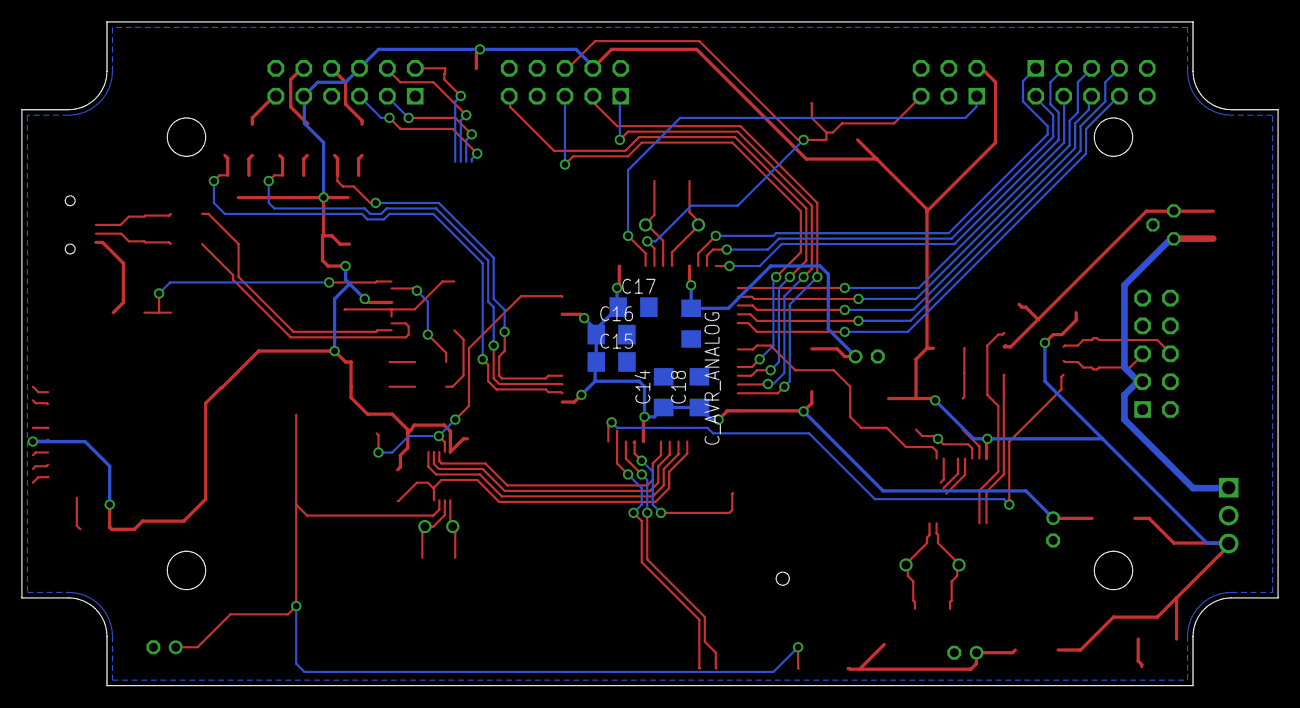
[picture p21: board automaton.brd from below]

Board: 2 copper layers, 114.5 x 60.5 mm, 82 parts (6 on the bottom side), 84 nets.

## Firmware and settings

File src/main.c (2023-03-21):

/* automaton
 * (c) 2014 Justin Gottula
 * The source code of this project is distributed under the terms of the
 * simplified BSD license. See the LICENSE file for details.
 */


#include "std.h"
#include "dev/can/can.h"
#include "dev/gps/gps.h"
#include "dev/gps/uart.h"
#include "dev/lcd/backlight.h"
#include "dev/lcd/font.h"
#include "dev/lcd/lcd.h"
#include "dev/uart/uart.h"
#include "mcu/clock.h"
#include "mcu/pmic.h"
#include "obd/obd.h"


int main(void) {
	mcu_setup_xtal();
	mcu_setup_pll();
	mcu_use_pll();
	
	pmic_init();
	
	uart_init();
	stdfile_open();
	
	
	lcd_bl_init();
	//button_init();
	
	lcd_init();
	lcd_onoff(true);
	lcd_contrast(0x18);
	lcd_bl_rgb(255, 255, 255);
	
	fputs_P(PSTR("\nhello from automaton!\n"), stdout);
	
	
	/*fputs_P(PSTR("This is a\nGREAT PROJECT"), lcd);
	lcd_update(false);
	
	
	lcd_bl_rgb(255, 0, 0);
	for (;;) {
		for (uint8_t i = 0; i < 255; ++i) {
			lcd_bl_rgb(255, i + 1, 0);
			_delay_ms(2);
		}
		for (uint8_t i = 0; i < 255; ++i) {
			lcd_bl_rgb(255 - (i + 1), 255, 0);
			_delay_ms(2);
		}
		for (uint8_t i = 0; i < 255; ++i) {
			lcd_bl_rgb(0, 255, i + 1);
			_delay_ms(2);
		}
		for (uint8_t i = 0; i < 255; ++i) {
			lcd_bl_rgb(0, 255 - (i + 1), 255);
			_delay_ms(2);
		}
		for (uint8_t i = 0; i < 255; ++i) {
			lcd_bl_rgb(i + 1, 0, 255);
			_delay_ms(2);
		}
		for (uint8_t i = 0; i < 255; ++i) {
			lcd_bl_rgb(255, 0, 255 - (i + 1));
			_delay_ms(2);
		}
	}*/
	
	
	gps_uart_init();
	//gps_test();
	#warning come back to this!
	
	
	// groovy colors
	/*lcd_bl_rgb(255, 0, 0);
	for (;;) {
		for (uint8_t i = 0; i < 255; ++i) {
			lcd_bl_rgb(255, i + 1, 0);
			_delay_ms(2);
		}
		for (uint8_t i = 0; i < 255; ++i) {
			lcd_bl_rgb(255 - (i + 1), 255, 0);
			_delay_ms(2);
		}
		for (uint8_t i = 0; i < 255; ++i) {
			lcd_bl_rgb(0, 255, i + 1);
			_delay_ms(2);
		}
		for (uint8_t i = 0; i < 255; ++i) {
			lcd_bl_rgb(0, 255 - (i + 1), 255);
			_delay_ms(2);
		}
		for (uint8_t i = 0; i < 255; ++i) {
			lcd_bl_rgb(i + 1, 0, 255);
			_delay_ms(2);
		}
		for (uint8_t i = 0; i < 255; ++i) {
			lcd_bl_rgb(255, 0, 255 - (i + 1));
			_delay_ms(2);
		}
	}*/
	
	
	//can_init();
	obd_test();
	
	
	// TODO: test 16-bit fifo functions
	// TODO: test ASSERT()
	
	
	/*uart_direct_write_pstr(UART_PC, UART_DIV_PC,
		PSTR("\n[[automaton][pc uart]]\n"));
	
	
	timer1_start();
	
	uart_init(UART_PC, UART_DIV_PC, 0, 0);
	stdfile_open();
	
	sei();
	fputs_P(PSTR("main: uart ok\n"), stdout);
	
	
	_main_init(PSTR("lcd"));
	lcd_init();
	
	fputs_P(PSTR("init..."), lcd);
	
	_main_init(PSTR("clock"));
	clock_init();
	
	_main_init(PSTR("button"));
	button_init();
	
	_main_init(PSTR("spi"));
	spi_init();
	
	_main_init(PSTR("sd"));
	sd_init();
	
	fputs_P(PSTR("\rinit stn1110..."), lcd);
	
	_main_init(PSTR("stn1110"));
	stn1110_init();
	
	lcd_clear();
	fputs_P(PSTR("main: init ok\n"), stdout);
	
	
	_DEBUG_passthru_uart();
	
	
	ui_loop();*/
	
	die();
}

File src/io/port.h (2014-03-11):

/* automaton
 * (c) 2014 Justin Gottula
 * The source code of this project is distributed under the terms of the
 * simplified BSD license. See the LICENSE file for details.
 */


#ifndef AUTOMATON_IO_PORT_H
#define AUTOMATON_IO_PORT_H


#include "std.h"


//#define REG_MODIFY(_reg, _mask, _val) \
// 	(_reg) = (((_reg) & ~(_mask)) | ((_val) & (_mask)))


/* pinout:
PA0-7: BTN_0-7

PB0: SD_DAT1
PB1: SD_DAT2
PB2: CAN_INT
PB4-7: JTAG_TMS, _TDI, _TCK, _TDO

PC0-3: LCD_RESET, _SCK, _A0, _SID
PC4-7: RTC_SS, _MOSI, _MISO, _SCK
USARTC0 (SPI master mode): LCD
SPIC: RTC

PD0: GPS_1HZ
PD1: CAN_STANDBY
PD2-3: GPS_TX, _RX
PD4-7: CAN_SS, _MOSI, _MISO, _SCK
USARTD0: GPS
SPID: CAN

PE0-2: LCD_BL_B-, _G-, _R-
PE3-7: SD_DETECT, _SS, _MOSI, _MISO, _SCK
SPIE: SD

PF1: RTC_INT
PF2-5: FTDI_TXD, _RXD, _RTS#, _CTS#
USARTF0: FTDI
*/


#if 0
#define DDR(_x) \
	CONCAT(DDR, _x)
#define PORT(_x) \
	CONCAT(PORT, _x)
#define PIN(_x) \
	CONCAT(PIN, _x)


#define IO_LCD_BUS  A
#define IO_BTN      A
#define IO_RTC      B
#define IO_SD       B
#define IO_SPI      B
#define IO_LED      D
#define IO_LCD_CTRL D


enum io_port_a {
	IO_LCD_BUS_ALL = _BV(PA0) | _BV(PA1) | _BV(PA2) | _BV(PA3),
	
	/* these must be contiguous */
	IO_BTN_A     = _BV(PA4),
	IO_BTN_B     = _BV(PA5),
	IO_BTN_C     = _BV(PA6),
	IO_BTN_D     = _BV(PA7),
	IO_BTN_ALL   = IO_BTN_A | IO_BTN_B | IO_BTN_C | IO_BTN_D,
	IO_BTN_FIRST = IO_BTN_A,
};

enum io_port_b {
	IO_RTC_IO   = _BV(PB0),
	IO_RTC_SCLK = _BV(PB1),
	IO_RTC_CE   = _BV(PB2),
	IO_RTC_ALL  = IO_RTC_IO | IO_RTC_SCLK | IO_RTC_CE,
	
	IO_SD_DETECT = _BV(PB3),
	
	/* warning: don't set PB4 as input, or spi master mode may be disabled */
	IO_SPI_SS_SD  = _BV(PB4),
	IO_SPI_SS_ALL = IO_SPI_SS_SD,
	
	IO_SPI_MOSI = _BV(PB5),
	IO_SPI_MISO = _BV(PB6),
	IO_SPI_SCK  = _BV(PB7),
	IO_SPI_ALL  = IO_SPI_MOSI | IO_SPI_MISO | IO_SPI_SCK,
};

/*enum io_port_c {*/
	/* PC2: JTAG */
	/* PC3: JTAG */
	/* PC4: JTAG */
	/* PC5: JTAG */
/*};*/

enum io_port_d {
	/* PD0: UART0 rx */
	/* PD1: UART0 tx */
	/* PD2: UART1 rx */
	/* PD3: UART1 tx */
	
	IO_LCD_CTRL_E   = _BV(PD4),
	IO_LCD_CTRL_RW  = _BV(PD5),
	IO_LCD_CTRL_RS  = _BV(PD6),
	IO_LCD_CTRL_ALL = IO_LCD_CTRL_E | IO_LCD_CTRL_RW | IO_LCD_CTRL_RS,
	
	IO_LED_0   = _BV(PD7),
	IO_LED_ALL = IO_LED_0,
};
#endif


#endif

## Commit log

2013-03-27 redo: add -F flag to avrdude invocation to avoid device id issues
2013-03-29 uart: implement basic functionality
2013-03-29 uart: make it work
2013-03-29 debug: add reset function
    [main.c]
2013-04-03 iso: implement rudimentary uart controls
2013-04-06 time/alarm: implement timeout alarm using TIMER1
2013-04-07 algo/fifo: implement interrupt-safe circular buffer
2013-04-07 io/uart: mostly implement fancy new uart system
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2013-04-07 io/uart: finish interrupt handler implementation
2013-04-07 io/uart: add missing dev param to uart_write_pstr macro
2013-04-07 io/uart: fix wrong function name in uart_write_pstr macro
2013-04-07 main: initialize uart and lcd
2013-04-07 io/uart: remove code gen warning
2013-04-07 io/uart: return characters read in all uart_{read,write}_*
2013-04-07 debug/stdfile: set stdin and stdout to use the debug uart
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2013-04-07 io/uart: remove non-character functions
2013-04-07 debug/die: call uart_flush on UART_DEBUG
2013-04-07 io/uart: reorder uart_divisor members
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2013-04-07 debug/stdfile: update for bool return type of uart functions
2013-04-07 obd/stn1110: implement uart file functionality
2013-04-07 README: increase pessimism wrt board manufacture
2013-04-07 io/uart: remove redundant _chr suffix on read/write functions
2013-04-07 lcd/hd44780: fix typo in friendly ID bit enum
    [hd44780.h]
2013-04-08 io/led: add basic led debugging ability (and LED_BLOCK hackery)
2013-04-12 io/uart: reorder tx and rx in struct uart for consistency
2013-04-12 io/io: add DS1302 spi ss line
2013-04-12 io/spi: add params for DS1302 (with implied 3-wire to spi circuit)
2013-04-12 io/uart: rename UART_DEBUG to UART_PC
2013-04-12 io/uart: check for initialized state in public functions
2013-04-12 io/uart: add uart_avail prototype to header
2013-04-12 io/uart: turn on UDRE interrupt only when wanted
2013-04-12 io/uart: add fifo and interrupt count debug code
2013-04-12 io/uart: disable fifo debugging
2013-04-12 io/uart: move debug definitions below includes
2013-04-12 io/uart: don't clear entire lcd every time on debug output
2013-04-13 algo/fifo: enable interrupts while waiting
2013-04-13 io/uart: include lcd header regardless of debug status
2013-04-13 io/uart: remove needless duplication of fifo calls
2013-04-13 io/uart: correct uart_init zero timeout documentation
    [uart.c]
2013-04-13 io/uart: reorder tx operations; don't prime the pump
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2013-04-13 io/uart: eliminate tx wait stuff
2013-04-13 io/uart: handle non-printable and CR/LF chars in uart fifo debug
2013-04-13 io/uart: do clear the lcd before writing for fifo debugging
2013-04-13 io/uart: use lcd_write instead of fputc
2013-04-13 io/uart: add some more int flag debug statements
2013-04-17 redo: major overhaul
    add description to file header
    document avr-gcc 4.8 brokenness
    compute avrdude flags dynamically
    source configuration files for microcontroller and programmer
    move -std=gnu11 to CFLAGS_STD
    add -Wl,--gc-sections
    remove -Waddr-space-convert (avr-gcc 4.8 specific)
    remove -fno-diagnostics-show-caret (avr-gcc 4.8 specific)
    combine CFLAGS parts array-wise to avoid extra spaces
    remove OUT_HEX target
    program OUT_BIN directly
    make quotes more consistent
    add fuse avrdude target
    add term avrdude target
2013-04-18 cfg/atmega324a: switch to full-swing oscillator (fixed sporadic issues)
2013-04-18 lcd/lcd: track initialization and don't block if uninitialized
2013-04-18 io/uart: handle LF/CR transformations in stdfile wrappers
2013-04-18 obd/stn1110: don't use uart timeouts
2013-04-20 io/uart: add baud rate divisor constants for 10 MHz
2013-04-20 io/spi: add clock divider constants for 10 MHz
2013-04-20 io/uart: fix 115200 baud divisor for 10 MHz
2013-04-20 io/uart: add baud divisors for 300, 600, 1200 baud
2013-04-20 io/uart: add note regarding clearing of state upon re-init
2013-04-20 debug: move _BREAK from assert() into die(), after uart_flush()
2013-04-20 debug/die: wait 1000ms for uart flush
2013-04-23 cfg: add uart config tentatively
2013-04-23 doc/vehicle: add some corolla pid data
    [corolla.ods]
2013-04-23 io/spi: document IO port settings
2013-04-23 time/alarm: assert to protect against double-arm condition
2013-04-23 uart/uart: move from io/uart
2013-04-23 uart/direct: implement simple, synchronous uart write interface
2013-04-23 debug/assert: make use of uart/direct
2013-04-23 uart/direct: add LF -> CRLF conversion
2013-04-27 time/timer0: implement generic millisecond timer
2013-04-27 time/alarm: reimplement using timer0 (multiple alarms okay now)
2013-04-27 uart/uart: update for alarm and fifo changes
2013-04-27 uart/direct: completely flush after every public write call
2013-04-27 button/button: implement robust button system
2013-04-27 io/io: define button pins
2013-04-27 io/spi: set pull-ups before input mode
2013-04-27 button/button: set pullups before input mode
2013-04-27 lcd/hd44780: fix scope error due to ATOMIC_BLOCK insertion
2013-04-27 rtc/ds1302: implement 3-wire protocol via bitbang
2013-04-27 button/button: remove testing reminder
2013-04-27 time/timer0: rename hooks called by timer0 isr
2013-04-27 debug/reset: bring back reset_defuse
    [main.c]
2013-04-27 rtc/ds1302: remove debug printf's
2013-04-28 time/clock: remove timer0 hook warning
2013-04-28 lcd/lcd: replace xy cursor handling with rc
    [uart.c]
2013-04-29 rtc/rtc: filter incoming data bits
2013-04-29 button/button: rename button_event function to button_pump
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2013-08-11 time: move millisecond tick to TIMER1 (better precision for clock ticks)
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2013-09-04 io/spi: rewrite so SPI interrupts are enabled on a short-term basis
    [spi.c, spi.h]
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2014-02-12 check in version 3 changes
    [automaton.brd, automaton.sch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]
2014-02-13 README: bring up-to-date for PCB version with hardware changes
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2014-02-13 io/port: fix LCD_BL_{R,B}- order
    [port.h]
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2014-02-14 dev/lcd/lcd: track modified page/column ranges and update efficiently
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2014-02-27 algo/fifo: add push_force functions for UART TX use
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2014-02-27 mcu/reset: make consistent with changes to mcu/die
2014-02-27 algo/fifo: fix wrong return types for _force functions in header prototype
2014-02-27 dev/uart/uart: rewrite and simplify for FTDI use only
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2014-03-10 dev/uart/uart: fix bad math for BSCALE in BAUDCTRLB
    [uart.c]
2014-03-10 dev/lcd/spi: fix bad BSEL math and horrendously wrong assignment
    [spi.c]
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2014-03-10 dev/uart/uart: change RXC int priority from high to medium
2014-03-10 dev/uart/uart: revert RXC int priority change
    [uart.c]
2014-03-10 dev/can/spi: implement basic SPI functions for MCP2515 use
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2014-03-11 io/port: fix incorrect PORTD assignments
    [port.h]
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2014-03-11 std: add mcu/die.h and mcu/reset.h
2014-03-11 main: add die() to end so things get flushed properly
2014-03-11 dev/uart/uart: fix uart_write always returning false
    [uart.c]
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2014-03-26 obd/obd: perform OBD-II mode 01 pid 00 test
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2014-03-27 hw/rev1-errata: add LED erratum
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2014-03-27 doc/vehicle/corolla: update incorrect PID (4b -> 4a)
    [corolla.ods]
2014-03-29 debug/assert: rewrite to use fatal; add more info to printout
2014-03-29 dev/uart/uart: add note to fix last character flush in uart_flush
    [uart.c]
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

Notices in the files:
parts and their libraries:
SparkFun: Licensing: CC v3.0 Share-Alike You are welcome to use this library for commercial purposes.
